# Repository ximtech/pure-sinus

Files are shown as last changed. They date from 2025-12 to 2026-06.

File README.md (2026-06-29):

# Pure-Sinus

The purpose of this project is to provide universal solutions for portable power stations, battery chargers, and inverters. 

## Table of Contents

- [Solr Mobile Power Management Platform](#solr-mobile-power-management-platform)
- [Solr Battery Controller](#solr-battery-controller)

# Solr Mobile Power Management Platform

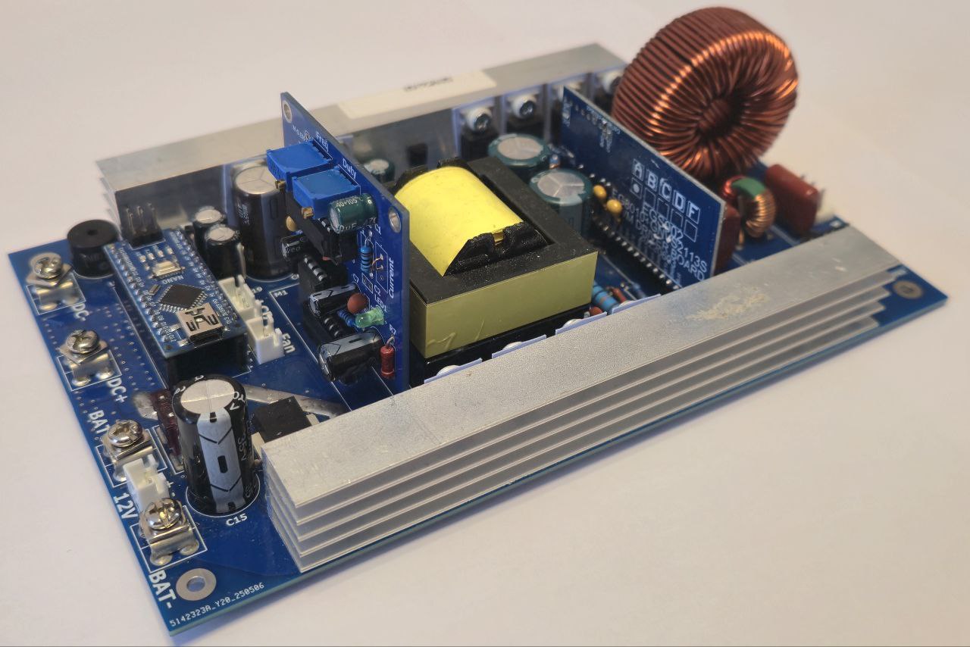
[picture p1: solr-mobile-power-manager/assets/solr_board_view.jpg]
solr_board_view


A compact and powerful battery-powered control electronics system with output power up to 500W. 
It can also be used as a standalone pure sine wave inverter converting 12V DC to 220V AC.
The system includes intelligent monitoring, protection, and management features for safe and reliable portable power delivery.

### Key Features

- **Pure Sine Wave AC Output**: 220V 50Hz AC up to 500W
- **500W Power Rating**: Sufficient for charging multiple devices and powering small appliances
- **DC Output**: 12V DC with up to 180W output for USB charging and DC loads
- **Lithium 3S 12V Battery Input**
- **Intelligent Power Management System**:
  - **Real-time battery voltage monitoring**: Low-battery protection with hysteresis
  - **Overload & Short-Circuit Protection**
  - **Dual Current Sensing**: Independent monitoring of DC output and AC inverter currents
  - **Dual Temperature Monitoring**: With automatic fan control and overheat protection
  - **Bidirectional DC**: DC output can also be used as a battery charger
  - **Low power consumption in standby mode**
- **Portable & Modular**: Designed as a platform for expanding functionality

### Use Cases

✓ **Device Charging**: Portable charging station for phones, tablets, and laptops  
✓ **Power Tools**: Supply stable AC power to cordless tools and equipment  
✓ **Emergency Power**: Backup power for critical devices during outages  
✓ **Outdoor Adventures**: Portable power for camping, RVs, and off-grid scenarios  
✓ **IoT & Smart Devices**: Reliable power for home automation and smart systems  

### Project Structure

```
pure-sinus/
└── solr-mobile-power-manager/         # Main folder
    ├── assets/                        # Images and visual assets
    ├── documents/                     # Datasheets and technical documentation
    ├── altium/                      # Altium PCB designs and circuit schematics
    │   ├── inverter_12V_220V_500W/    # Main inverter/power station board
    │   │   ├── Fabrication Files/     # Gerber, BOM, and manufacturing files
    │   │   └── libs/                  # Component libraries for Altium Designer
    │   └── tl494_pwm_controller/      # Dedicated PWM controller module
    │       ├── Fabrication Files/     # Gerber, BOM, and manufacturing files
    │       └── libs/                  # Component libraries for Altium Designer
    └── software/                      # PlatformIO firmware and control logic
        └── inverter-controller/       # Arduino firmware (PlatformIO-based)
            ├── src/                   # Source code files
            ├── include/               # Header files and configuration
            ├── lib/                   # Custom and external libraries
            ├── test/                  # Unit tests
            └── platformio.ini         # PlatformIO project configuration
```

### Hardware Specifications

### Main Components

- **Microcontroller**: Arduino Nano (ATmega328P)
- **PWM Controller**: TL494 PWM IC (with custom dedicated module)
- **Pure Sinus Driver**: EGS002
- **Current Sensors**: 
  - ACS712 30A Hall-effect current sensor DC
  - ACS758 100A Hall-effect current sensor AC
- **Temperature Sensors**: LM35
- **Output Transformer**: EC42-20 High-frequency SMPS transformer (12V→380V conversion)

### Hardware Assembly

### 1. TL494 PWM Module Assembly And Setup

- `pwm_controller_board.rar` contains all required files for PCB manufacturing the TL494 PWM module and located in `/altium/tl494_pwm_controller/Fabrication Files`
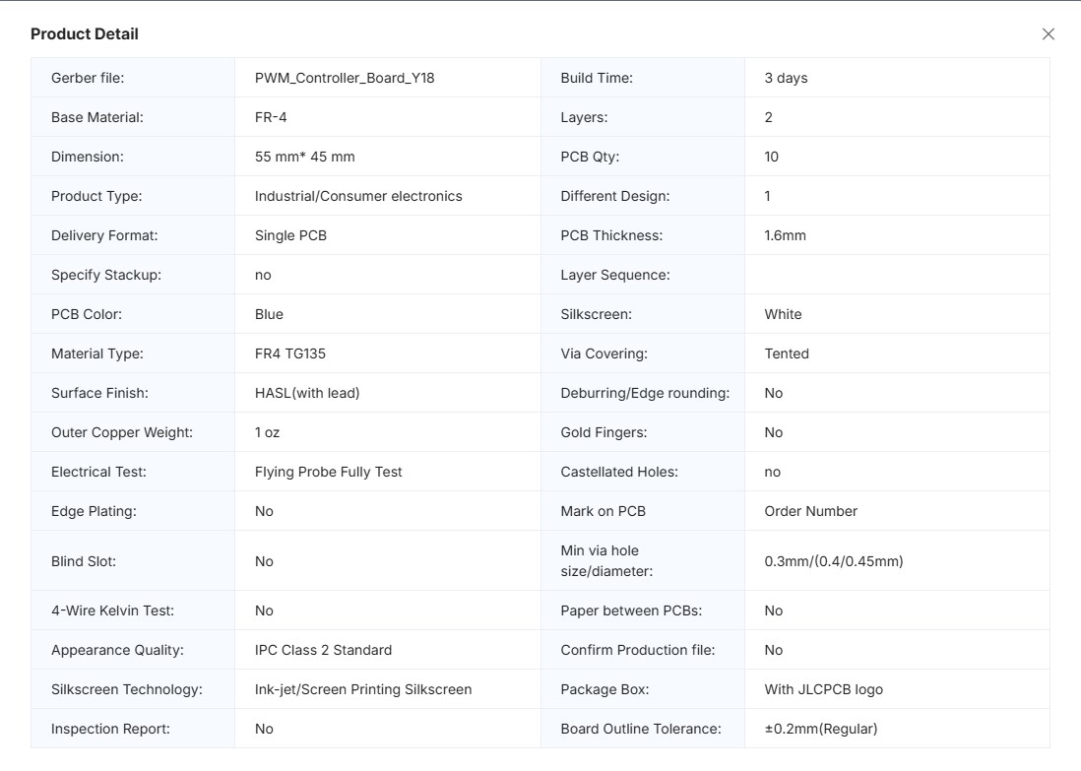
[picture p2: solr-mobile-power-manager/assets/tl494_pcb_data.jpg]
pcb_request_data
- 
- Follow the provided BOM and Gerber files to fabricate and assemble the PWM module
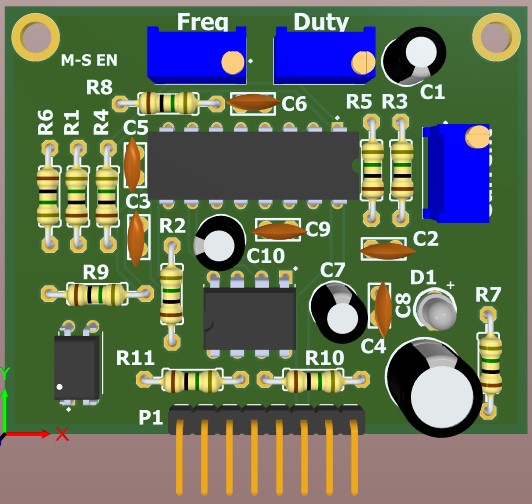
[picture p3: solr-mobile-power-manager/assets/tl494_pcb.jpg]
tl494_pcb
- 
- PWM module setup: 
    - Connect 12V power supply to `+12V` and `GND`
    - Set the frequency to `32kHz` for outputs `OutA` and `OutB` using potentiometer `Freq`
    - Adjust potentiometer `Duty` for `42%` duty cycle at no load
    - No need to configure current limiter, so `I-Sense` pin can be connected directly to ground
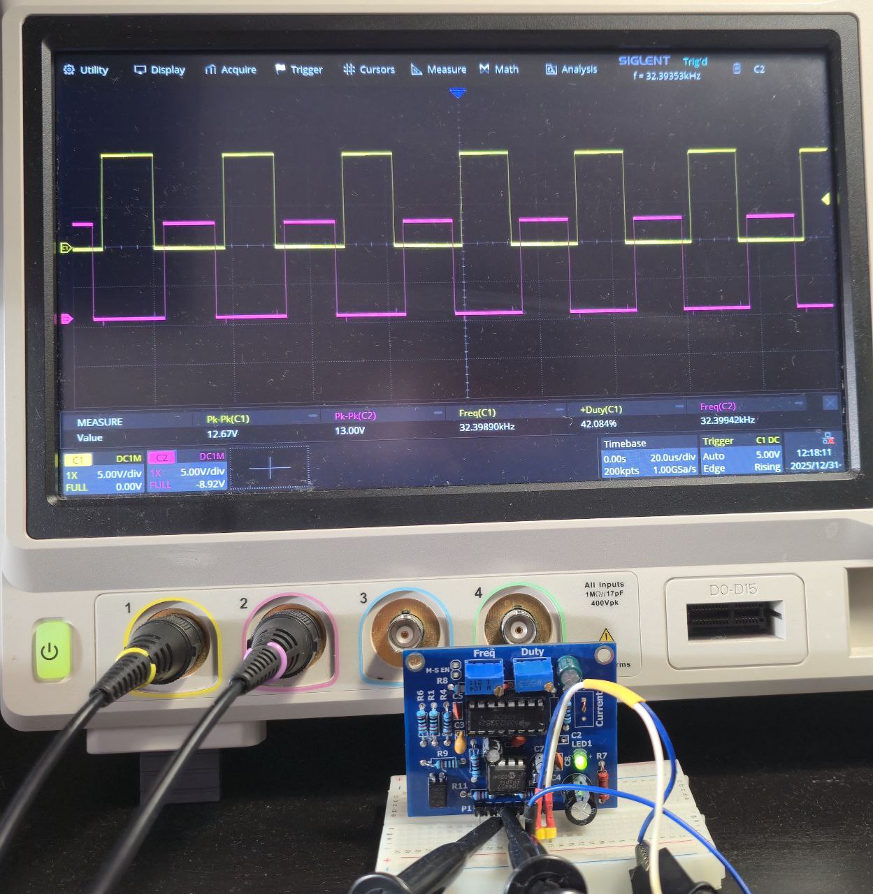
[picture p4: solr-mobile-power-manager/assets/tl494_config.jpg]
tl494_config
- 

### 2. EGS002 Driver Module Setup

The EGS002 module handles pure sinus wave generation
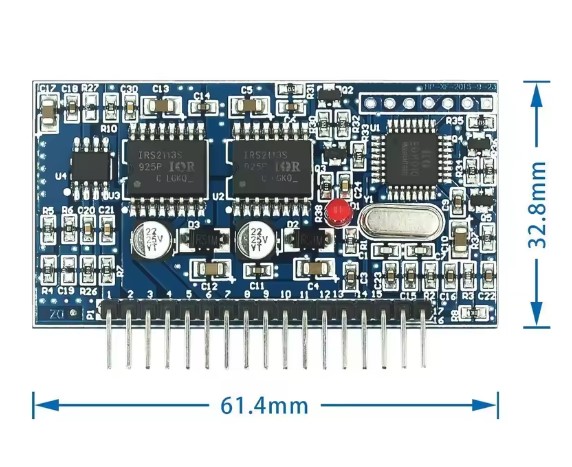
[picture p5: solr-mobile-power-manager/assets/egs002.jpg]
egs_pcb
- 
- Solder `JP8` jumper to `JP4`, to set dead time for `1.0us`
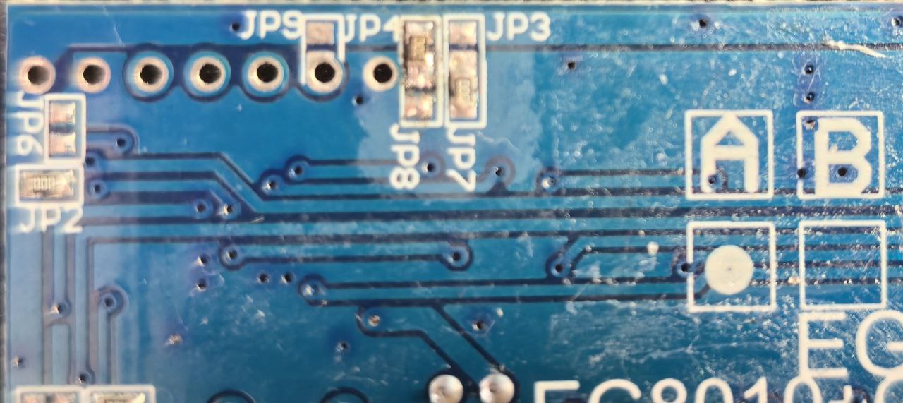
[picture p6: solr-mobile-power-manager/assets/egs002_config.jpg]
egs_pcb_config
- 
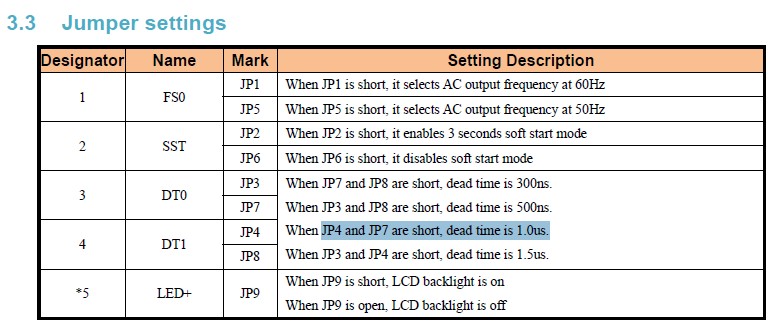
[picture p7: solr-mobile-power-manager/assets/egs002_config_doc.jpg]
egs_pcb_config_doc
- 
- No additional configuration is required

### 3. Inverter Board Assembly And Setup

- `inverter_board.rar` contains all required files for PCB manufacturing the board and located in `/altium/inverter_12V_220V_500W/Fabrication Files/`
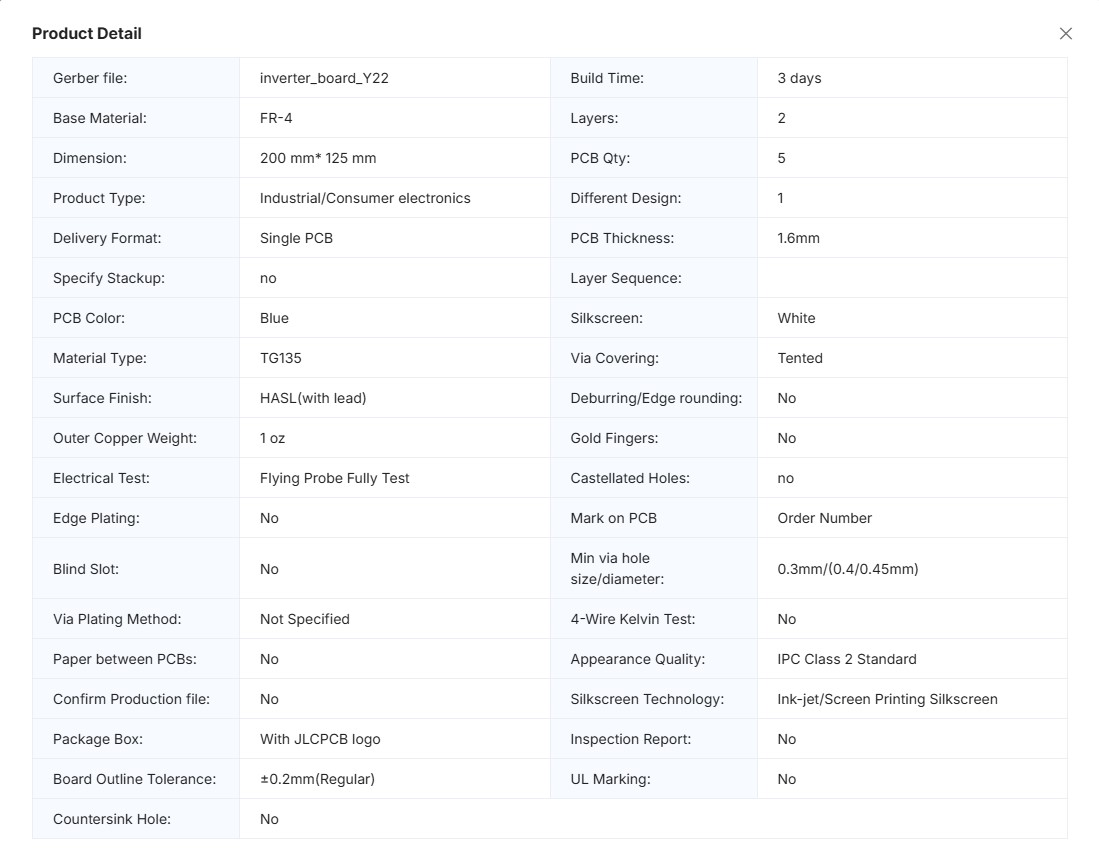
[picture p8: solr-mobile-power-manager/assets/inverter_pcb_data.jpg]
inverter_pcb_request_data
- 
- Follow the provided BOM and Gerber files to fabricate and assemble the PCB
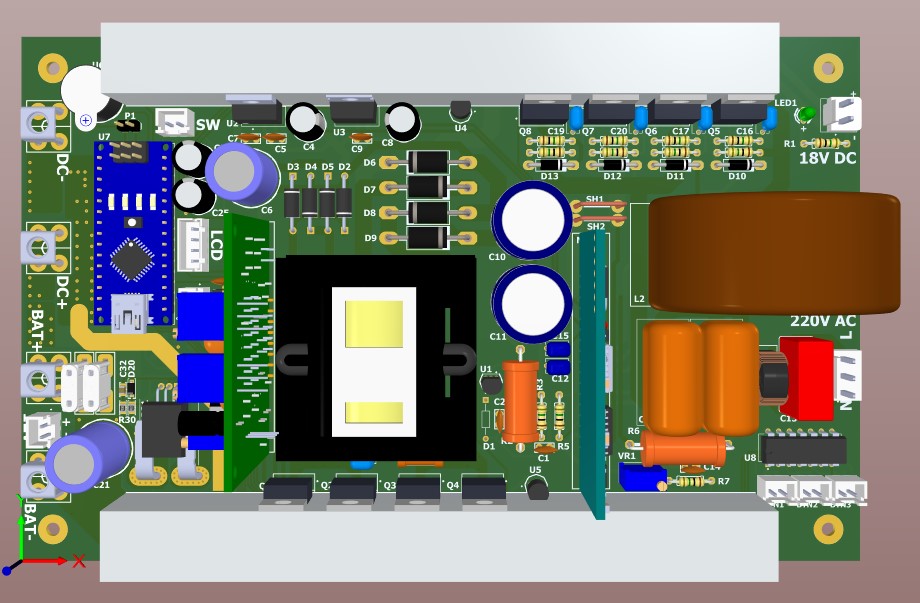
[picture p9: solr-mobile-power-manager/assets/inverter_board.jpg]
inverter_board
- 

### Assembly Steps

1. First, solder all SMD components on top and bottom layers
2. Solder all components, except `C6, C10, C11, T1, C21, M1 and M2`
3. Place heat sink `HS1` and `HS2`, then solder MOSFETs and LM78xx, secure with screws and isolating pads
4. Solder all other components except driver modules and Arduino
5. ***Note:*** It is recommended to use sockets for the microcontroller and driver modules for easy replacement and troubleshooting.
6. Then, connect/solder the `Arduino` and `TL494 PWM module`
7. Program the Arduino with the provided firmware
8. Connect laboratory power supply to `12V` input, set the current limit to `4-5A`, set `J8` switch and power on the board
9. Measure HV output voltage, it should be `400V DC` with no load and no `EGS002` module connected
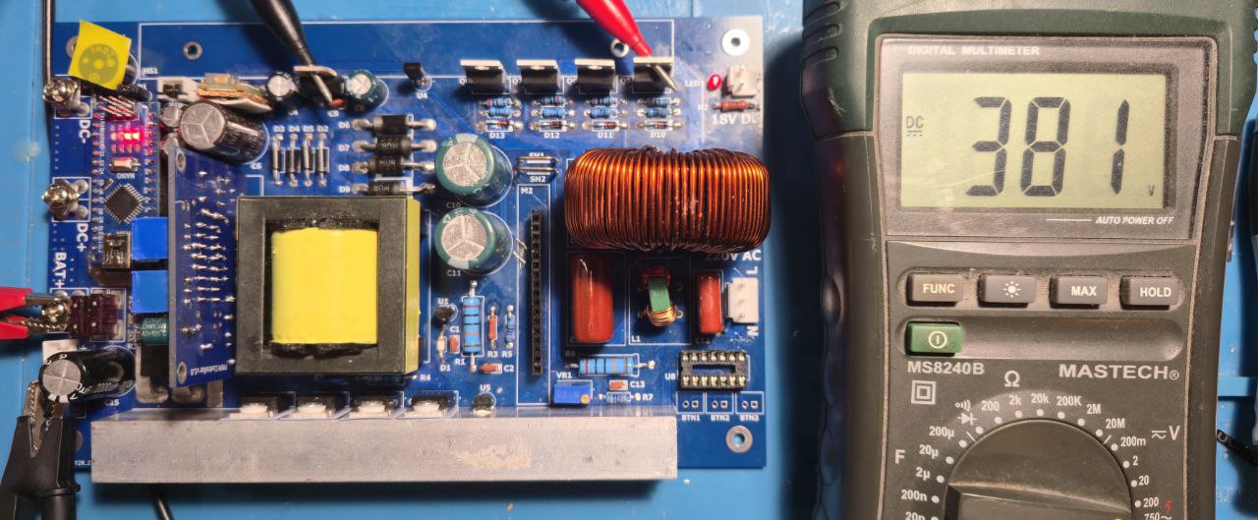
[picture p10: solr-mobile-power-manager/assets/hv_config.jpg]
hv_config
- 
10. Turn off power supply and wait(`R2` also used as bleed resistor) or discharge HV capacitors `C10` and `C11` before connecting the `EGS002` module
11. Connect the `EGS002`, run the next time. `EGS002` led should be on continuously indicating normal operation
12. Measure the output `AC` voltage, adjust the `VR1` potentiometer to set output voltage to `230V AC`
13. Check output `AC` waveform with oscilloscope, it should be a clean sine wave, also check with a load connected
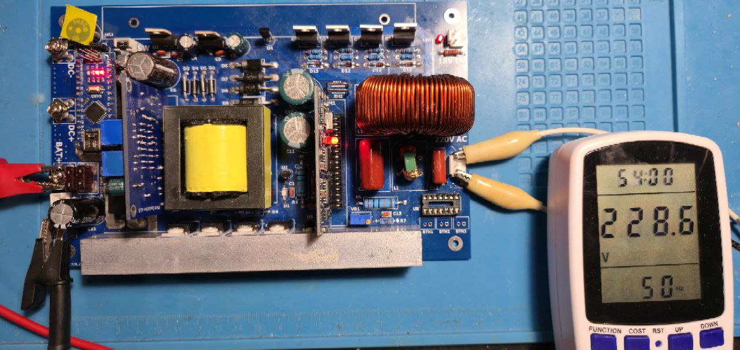
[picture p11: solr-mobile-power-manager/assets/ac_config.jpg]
ac_config
- 
14. Check `DC` voltage on `DC-` and `DC+` outputs, it should be `12V DC`
15. Connect cooling fan: it should run for a short time on power on, during system self-check
16. Then, set debug switch `P1` to on. Check ACS current sensors outputs, adjust if needed
17. Finally, glue thermal sensors to heat sinks using thermal adhesive glue (`heatsinkplaster`)
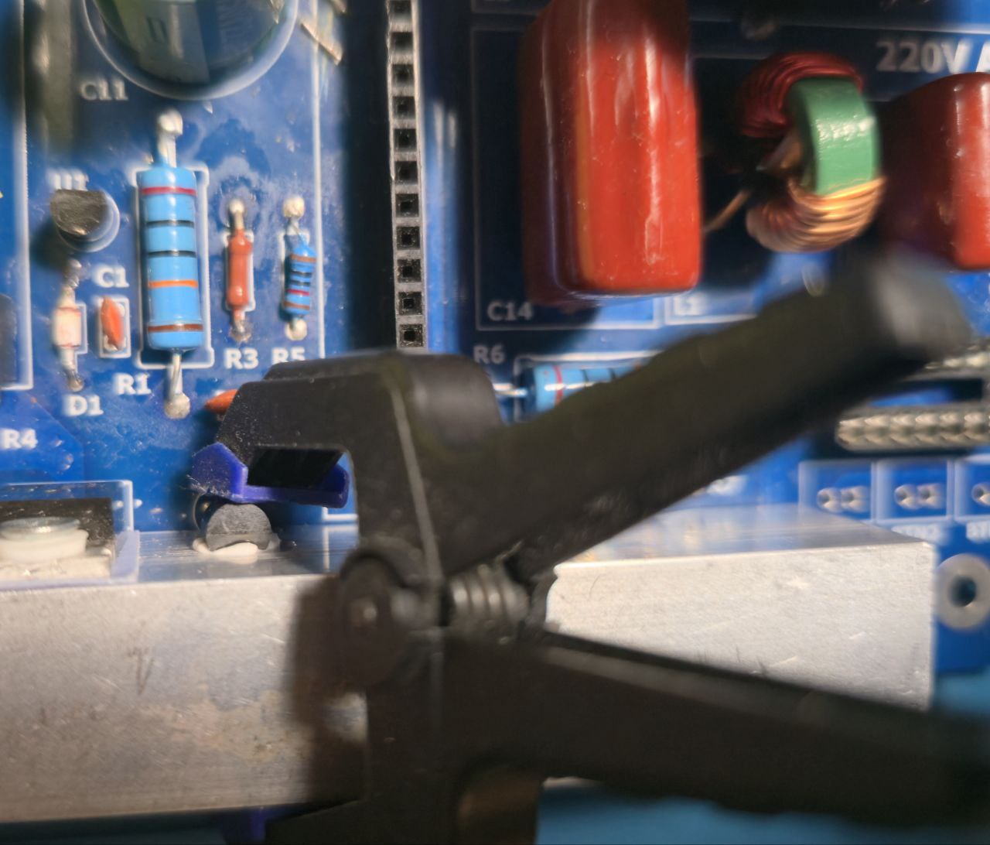
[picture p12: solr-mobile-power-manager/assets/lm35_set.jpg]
lm35_set
- 

### PCB Components
- Heat Sinks **HS1 and HS2** `150x19.7x15.6mm`: [link Aliexpress](https://www.aliexpress.com/item/1005004124759503.html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)
- Transformer **T1** `12V To 0-220V-380V 18V 500W EC42`: [link Aliexpress](https://www.aliexpress.com/item/1005003166892846.html?spm=a2g0o.order_list.order_list_main.5.2afd1802XkXKQq)
- Inductor **L2** `1.5 V. 2mH`: [link Aliexpress](https://www.aliexpress.com/item/1005006733553679.html?spm=a2g0o.order_list.order_list_main.382.6bd81802CETRoA)
- Choke filter **L1** `5A`: [link Aliexpress](https://www.aliexpress.com/item/33005799242.html?spm=a2g0o.order_list.order_list_main.65.6bd81802CETRoA)
- Capacitors **C10 and C11** `100uF 450V`: [link Aliexpress](https://www.aliexpress.com/item/1005006810057095.html?spm=a2g0o.order_list.order_list_main.362.6bd81802CETRoA)
- Shunt Resistor **SH1 and SH2** `20mR 1x10`: [link Aliexpress](https://www.aliexpress.com/item/1005005512229757.html?spm=a2g0o.order_list.order_list_main.372.6bd81802CETRoA)
- Screw terminal connectors **J3, J4, J5, J6**: [link Aliexpress](https://www.aliexpress.com/item/1005007060857910.html?spm=a2g0o.order_list.order_list_main.377.6bd81802CETRoA)
- Fuses **F1, F2** `25A`: [link Aliexpress](https://www.aliexpress.com/item/1005003956737422.html?spm=a2g0o.order_list.order_list_main.347.6bd81802CETRoA)
- The complete Bill of Materials (BOM) can be found in the `/altium/inverter_12V_220V_500W/Fabrication Files/` directory as `BOM_Inverter_12V_220V_500W.xlsx`.

### Firmware Architecture

Built with **PlatformIO** and **Arduino Framework** targeting Arduino Nano `ATmega328P`.

**Debug**:
- **When debug switch set**: 9600 baud UART can be used for monitoring and troubleshooting

## Safety Considerations And Warnings

### ⚠️ High Voltage Warning

This project operates with dangerous voltages

## Next Version Improvements

- ⬜ **OLED display and controls**: Add an OLED display and control buttons for monitoring and outputs on/off control
- ⬜ **Multi-Output USB**: Integrate USB-C and USB-A charging ports with PD protocol support, with up to 100W
- ⬜ **Battery Chemistry Flexibility**: Support for LiFePO4, Lead-acid, and other battery types
- ⬜ **Solar Input**: Add MPPT/PWM solar charge controller for renewable energy integration

---

# Solr Battery Controller

A universal `DC 12V 30A` battery controller.
The compact PCB design provides robust protection against battery over-discharge and over-current conditions,
ensuring maximum battery longevity and optimal performance with integrated power on delay feature.

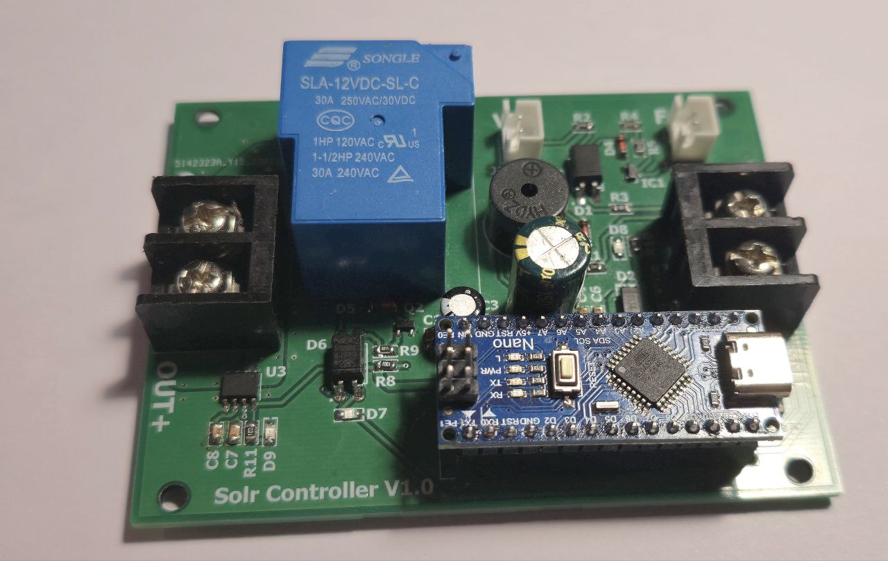
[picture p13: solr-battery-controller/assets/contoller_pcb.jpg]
solr_controller_pcb


### Key Features

- **Universal 12V Battery Compatibility**: Easy to set for various 12V battery types
- **Low Voltage Protection**: Detects and prevents dangerous voltage drops
- **Overcurrent Protection**: Output load disconnection on excessive current draw
- **Power On Delay**: Auto recovery after power interruptions with hysteresis, battery should be charged at least 10% for power on 
- **Mosfet Output**: Additional battery output that can be used for powering external devices or loads (`OUT` connector)
- **Charger Input**: Advanced charging algorithm for 12V batteries (`CHG` connector)
  - CV CC charger required (`XL4015` module), set charging voltage: 14.4V for SLA, 12.6V for Li-ion
- **Reverse Polarity Protection**
- **Compact Design**: 94mm x 70mm

### Project Structure

```
solr-battery-controller/               # Battery controller folder
├── assets/                            # Images and visual assets
├── documents/                         # Datasheets and technical documentation
├── altium/                            # Altium PCB designs and circuit schematics
│   └── solr-controller-base/          # Main controller board
│       ├── Fabrication Files/         # Gerber, BOM, and manufacturing files
│       └── *.IntLib                   # Component libraries for Altium Designer
└── software/                          # Firmware and control logic
    └── solr-controller-base/          # Arduino firmware (PlatformIO-based)
        ├── src/                       # Source code files
        ├── include/                   # Header files and configuration
        ├── lib/                       # Custom and external libraries
        ├── test/                      # Unit tests
        └── platformio.ini             # PlatformIO project configuration
```

### PCB Assembly

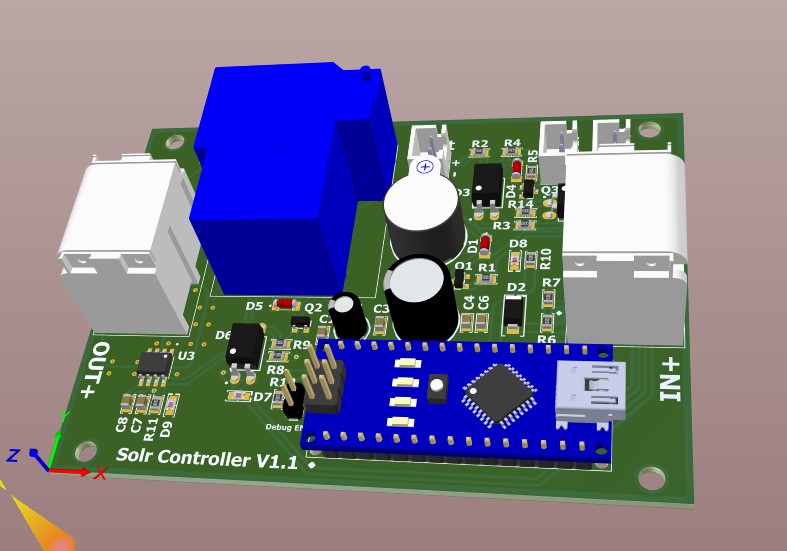
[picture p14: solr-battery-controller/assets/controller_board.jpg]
solr_controller_pcb
- 
- `solr-controller-board.rar` contains all required files for PCB manufacturing the board and located in `/altium/solr-controller-base/Fabrication Files/`
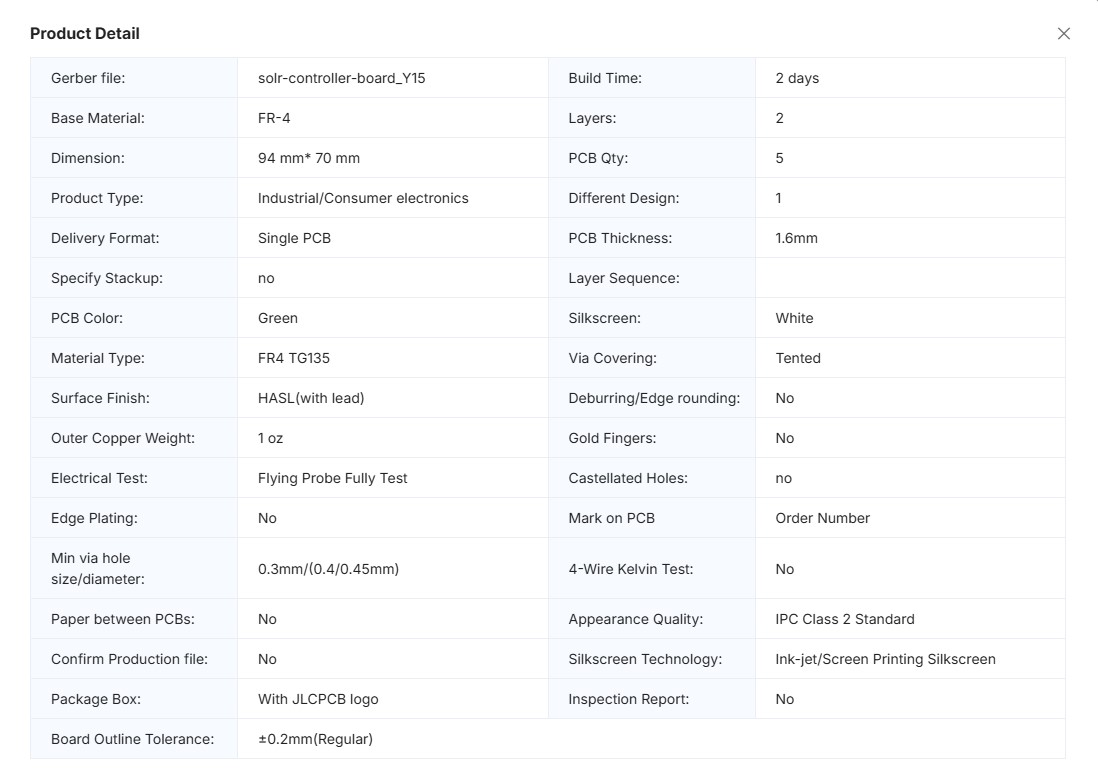
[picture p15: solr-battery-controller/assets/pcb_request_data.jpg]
solr_controller_pcb
- 

### PCB Components

- Relay **K1** `12V 30A`: [link Aliexpress](https://www.aliexpress.com/item/1005004371446685.html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)
- Connectors **J3 J4** `HB9500 2pin` : [link Aliexpress](https://www.aliexpress.com/item/1005008336461654.html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,scm-url:1007.40050.354490.0,pvid:bdbd0872-ae3c-45be-8bcf-08dd0156c3fc,tpp_buckets:668%232846%238111%231996&pdp_ext_f=%7B%22order%22%3A%22-1%22%2C%22eval%22%3A%221%22%2C%22sceneId%22%3A%2230050%22%2C%22fromPage%22%3A%22recommend%22%7D&pdp_npi=6%40dis%21EUR%210.50%210.50%21%21%210.58%210.58%21%40211b613917671256503675517e5ba9%2112000044644274242%21rec%21LV%21143434442%21XZ%211%210%21n_tag%3A-29919%3Bd%3A4c3c036e%3Bm03_new_user%3A-29895&utparam-url=scene%3ApcDetailTopMoreOtherSeller%7Cquery_from%3A%7Cx_object_id%3A1005008336461654%7C_p_origin_prod%3A)
- Current sensor **U3** `ACS712 30A`: [link Aliexpress](https://www.aliexpress.com/item/1005008877256845.html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)
- MCU **U2**: Arduino Nano (ATmega328P)
- The complete Bill of Materials (BOM) can be found in the `/altium/solr-controller-base/Fabrication Files/` directory as `BOM_Solr_Battery_Controller.xlsx`.

### Firmware Architecture

Built with **PlatformIO** and **Arduino Framework** targeting Arduino Nano `ATmega328P`.

**Debug**:
- **When debug switch set** `P1`: 9600 baud UART can be used for monitoring and troubleshooting

## Next Version Improvements

- ✅ **Battery Chemistry Flexibility**: Support for SLA, Li-ion

---

# Solr Button module

Universal two-button PCB module for controlling Solr input, also can be used for other applications. 
The module is designed to be compact and easy to integrate into various projects.

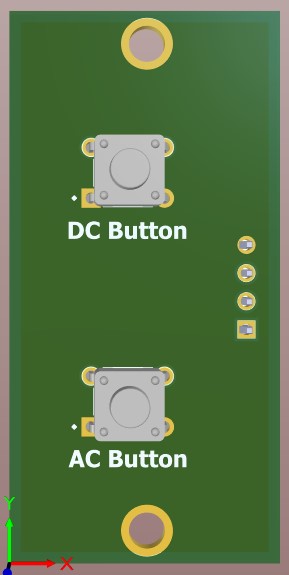
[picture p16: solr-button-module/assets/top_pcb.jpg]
solr_button_top_pcb
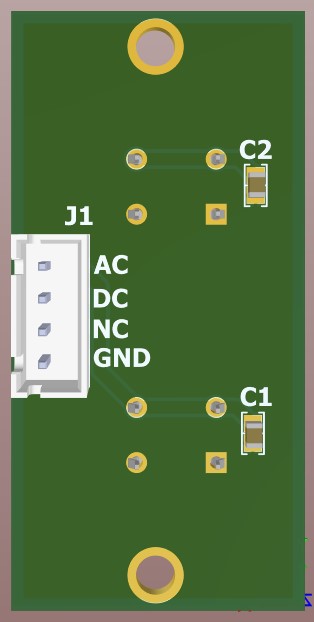
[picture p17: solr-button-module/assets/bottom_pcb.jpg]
solr_button_bottom_pcb


**Note:** Button dimensions are `6mm x 6mm` height `5mm`

---

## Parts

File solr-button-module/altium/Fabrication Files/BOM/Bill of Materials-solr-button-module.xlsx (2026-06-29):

Quantity | Designator | Comment | Footprint
2 | C1, C2 | 0.1µF | CAP 0805_2012
1 | J1 | B4B-XH-AM_(LF)(SN) | JST_B4B-XH-AM_(LF)(SN)
2 | S1, S2 | TL1105AF160Q | SW_TL1105AF160Q

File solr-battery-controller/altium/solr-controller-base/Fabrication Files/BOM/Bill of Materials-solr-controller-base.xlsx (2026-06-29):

Quantity | Designator | Comment | Footprint
3 | C1, C4, C7 | 0.1µF | CAP 0805_2012
1 | C2 | 100uF | MY_E5-13mm
2 | C3, C6 | 10 µF | CAP 0805_2012
1 | C5 | 1000u | MY_E5-13mm
1 | C8 | 1000 pF | CAP 0805_2012
4 | D1, D4, D5, D11 | LL4148 | DIO_LL4148
1 | D2 | SS23-TP | DO214AC SMA
3 | D3, D6, D10 | LTV-817S-TA | LITEON LTV-817
3 | D7, D8, D9 | Red | LED 0805_2012 RED
3 | J1, J2, J5 | B2B-XH-A(LF)(SN) | JST_B2B-XH-A(LF)(SN)
2 | J3, J4 | 5-1437648-7 | TE_5-1437648-7
1 | K1 | SLA-12VDC-SL-C | RELAY_SLA-12VDC-SL-C
1 | P1 | Header 2 | My_1X02
2 | Q1, Q2 | MMSS8050-L-TP | MCCSEMI SOT-23-3
1 | Q3 | DMG3406L-7 | DIODES SOT-23-3
1 | Q4 | AOD4184A | DPAK228P994X240-4N
2 | R1, R12 | 10 kOhms | RES 0805_2012
4 | R2, R5, R13, R16 | 4.7 kOhms | RES 0805_2012
5 | R3, R8, R10, R11, R14 | 1 kOhms | RES 0805_2012
2 | R4, R15 | 100 Ohms | RES 0805_2012
1 | R6 | 30 kOhms | RES 0805_2012
1 | R7 | 7.5 kOhms | RES 0805_2012
1 | R9 | 510 Ohms | RES 0805_2012
1 | U1 | Buzzer small | My_Buzzer
1 | U2 | Arduino Nano | MODULE_ARDUINO_NANO_A000005
1 | U3 | ACS712ELCTR30AT | SOIC127P600X175-8N

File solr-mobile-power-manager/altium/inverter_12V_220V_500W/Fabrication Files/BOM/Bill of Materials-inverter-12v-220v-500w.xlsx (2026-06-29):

Quantity | Designator | Comment | Footprint
6 | C1, C2, C5, C7, C9, C14 | 100nF | My_cap100n
1 | C3 | 10nF 1kV | CAP_RDER73A103K2K1H03B
2 | C4, C8 | 470uF | MY_E3.5-8mm
1 | C6 | 1000uF | MY_E5-13mm
2 | C10, C11 | 100uF | MY_E7.5-18mm
2 | C12, C15 | 10uF 25V | CAPRB500W50L550T350H600
1 | C13 | 100nF | MY_E8.4-15mm
4 | C16, C17, C19, C20 | 1nF 1kV | CAP_RDER73A103K2K1H03B
2 | C18, C42 | 2.2uF 630V | CAPRR2250W80L2530T1240H1770
1 | C21 | 2200uF | MY_E5-13mm
14 | C22, C23, C26, C27, C28, C29, C30, C32, C34, C35, C37, C41, C43, C44 | 0.1µF | CAP 0805_2012
2 | C24, C25 | 220uF | MY_E3.5-8mm
4 | C31, C33, C36, C39 | 10µF | CAP 0805_2012
1 | C38 | 100 pF | CAP 0805_2012
1 | C40 | 1000 pF | CAP 0805_2012
1 | D1 | BZX55B20_R0G | DIOAD928W47L399D179
4 | D2, D3, D4, D5 | HER207G | DIOAD1300W80L670D310
4 | D6, D7, D8, D9 | MUR460 | My_DO201-15
4 | D10, D11, D12, D13 | 1N4148 | My_DO41
3 | D14, D18, D21 | LTV-817S-TA | LITEON LTV-817
4 | D15, D17, D19, D22 | LL4148 | DIO_LL4148
1 | D16 | SS23-TP | DO214AC SMA
1 | D20 | MMSZ5231CT1G | SOD-123
2 | F1, F2 | 25A | Mini Car Blade Fuse
2 | HS1, HS2 | HSINK-150-20-16MM | HSINK-150-20-16MM
1 | J1 | 18V | VALCON_VH396-02S-010
1 | J2 | 220 VAC | JST_B3P-VH(LF)(SN)
1 | J3 | BATT + | Keystone 7767
1 | J4 | DC + | Keystone 7767
1 | J5 | BATT - | Keystone 7767
1 | J6 | DC - | Keystone 7767
1 | J7 | Out 12V | JST_B2B-XH-A(LF)(SN)
1 | J8 | On/Off Switch | JST_B2B-XH-A(LF)(SN)
1 | J9 | Buttons | JST_B4B-XH-AM_(LF)(SN)
1 | J10 | VH396-02S-010 | VALCON_VH396-02S-010
1 | J12 | Fan | JST_B2B-XH-A(LF)(SN)
1 | J13 | I2C | JST_B4B-XH-AM_(LF)(SN)
1 | L1 | 2mH | WE-CMBNC_XS_7448010911
1 | L2 | 2mH | 184125
1 | LED1 |  | LED3MM
1 | M1 | TL494 PWM Module | TL494-PWM-MODULE
1 | M2 | EGS002 | EGS002
1 | P1 | Debug EN | My_1X02
4 | Q1, Q2, Q3, Q4 | IRF3205PBF | INF-PG-TO-220AB
4 | Q5, Q6, Q7, Q8 | IRF840PBF | VISH-TO-220AB-3
6 | Q9, Q10, Q11, Q12, Q14, Q15 | AOD4184A | DPAK228P994X240-4N
1 | Q13 | MMSS8050-L-TP | MCCSEMI SOT-23-3
1 | Q16 | DMG3406L-7 | DIODES SOT-23-3
1 | R1 | 2.2 kOhms | MY_(0.25w)_0207_10
2 | R2, R6 | 200 kOhms | MY_(2w)_0617_22
1 | R3 | 3.3 kOhms | MY_(0.25w)_0207_10
1 | R4 | 4.7 Ohms | MY_(0.5w)_0411_15
2 | R5, R7 | 10 kOhms | MY_(0.25w)_0207_10
4 | R8, R9, R12, R13 | 22 Ohms | MY_(0.25w)_0207_10
4 | R10, R11, R14, R15 | 5.6 kOhms | MY_(0.25w)_0207_10
3 | R16, R23, R35 | 1 kOhms | RES 0805_2012
3 | R17, R27, R37 | 100 Ohms | RES 0805_2012
4 | R18, R28, R34, R38 | 4.7 kOhms | RES 0805_2012
8 | R19, R20, R21, R24, R25, R26, R33, R36 | 10 kOhms | YAGEO RES 0805_2012
2 | R22, R29 | 10 kOhms | RES 0805_2012
1 | R30 | 30 kOhms | RES 0805_2012
1 | R31 | 7.5 kOhms | RES 0805_2012
1 | R32 | 120 Ohms | YAGEO RES 0805_2012
2 | SH1, SH2 | 20 mOhms | WIRE-SHUNT
1 | T1 | EC42/EE42 | EC42/EE42
1 | U1 | TL431ILPG | TO92127P520H660-3
1 | U2 | LM7812CT | TO254P1054X470X1955-3
1 | U3 | LM7805CT | TO254P1054X470X2600-3
2 | U4, U5 | LM35DZ TO-92 | TO92127P521H735-3
1 | U6 | Buzzer small | My_Buzzer
1 | U7 | Arduino Nano | MODULE_ARDUINO_NANO_A000005
1 | U8 | CD74HC14E | DIP794W45P254L1969H508Q14
1 | U9 | TLC2272QDR | SOIC127P599X175-8N
1 | U10 | ACS712ELCTR30AT | SOIC127P600X175-8N
1 | U11 | ACS758 | XDCR_ACS758
1 | VR1 | 10k | TRIM_3296W-1-502

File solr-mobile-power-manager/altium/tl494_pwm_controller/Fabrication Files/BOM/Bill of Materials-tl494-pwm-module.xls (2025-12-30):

Quantity | Designator | Comment | Footprint
3 | C1, C7, C10 | 4.7uF | MY_E2.5-5mm
5 | C2, C3, C5, C8, C9 | 100nF | My_cap100n
1 | C4 | 220uF | MY_E3.5-8mm
1 | C6 | 1nF | My_cap100n
1 | D1 | LED | My_LED3MM
1 | P1 | Header 8 | MY_MA08-1W
6 | R1, R2, R6, R9, R10, R11 | 10 kOhms | MY_(0.25w)_0207_10
1 | R3 | 15 kOhms | MY_(0.25w)_0207_10
1 | R4 | 1 kOhms | MY_(0.25w)_0207_10
1 | R5 | 5.6 kOhms | MY_(0.25w)_0207_10
1 | R7 | 2.2 kOhms | MY_(0.25w)_0207_10
1 | R8 | 2 kOhms | MY_(0.25w)_0207_10
1 | U1 | PC817 | DIP762W50P254L495H455Q4
1 | U2 | TL494IN | DIP794W45P254L1969H508Q16
1 | U3 | MIC4427ZN | DIP787W46P254L927H533Q8
2 | VR1, VR2 | 10 kOhms | TRIM_3296W-1-502
1 | VR3 | 100 kOhms | TRIM_3296W-1-502

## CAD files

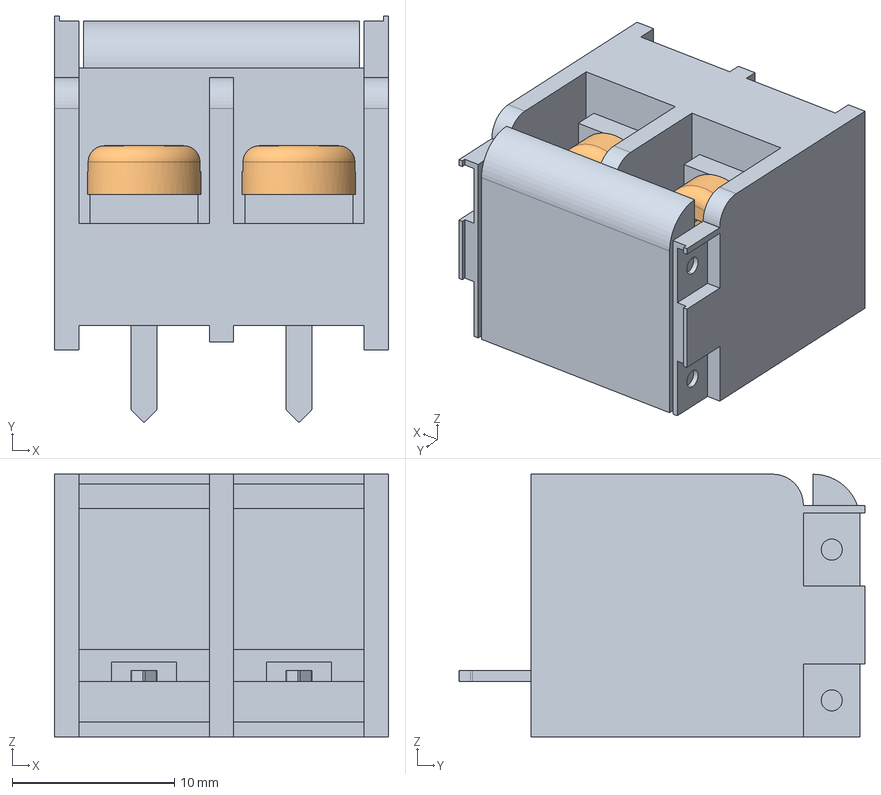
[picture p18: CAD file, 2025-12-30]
solr-battery-controller/altium/solr-controller-base/hb9500_asm.stp
20.6 x 25.0 x 16.2 mm
HB9500-1
M5X6 x 2

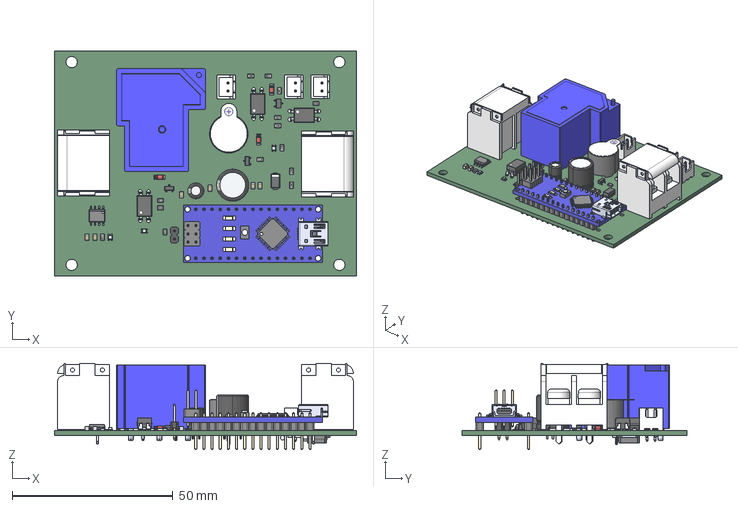
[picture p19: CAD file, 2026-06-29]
solr-battery-controller/altium/solr-controller-base/Fabrication Files/ExportSTEP/PCB.step
94.0 x 70.0 x 26.8 mm

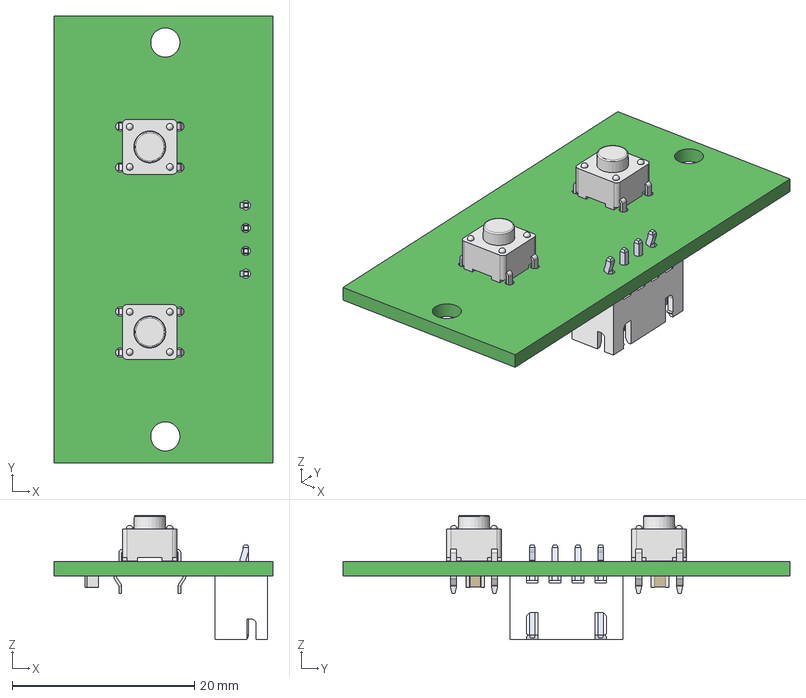
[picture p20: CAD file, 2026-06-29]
solr-button-module/altium/Fabrication Files/ExportSTEP/Buttons_PCB.step
24.0 x 49.0 x 13.6 mm

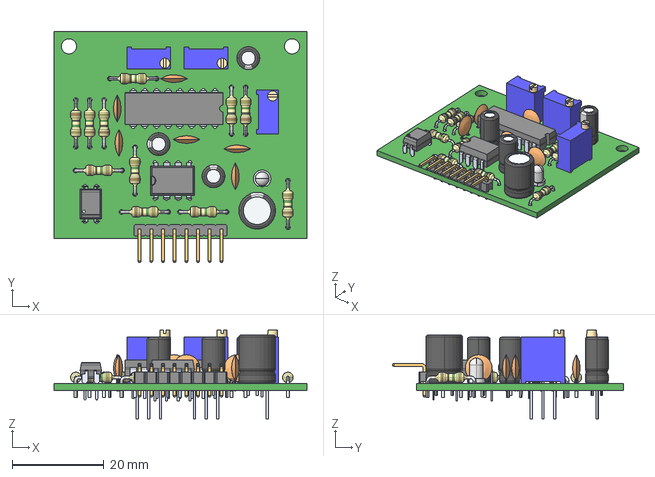
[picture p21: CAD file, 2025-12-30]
solr-mobile-power-manager/altium/tl494_pwm_controller/Fabrication Files/ExportSTEP/PCB.step
55.0 x 50.2 x 19.3 mm

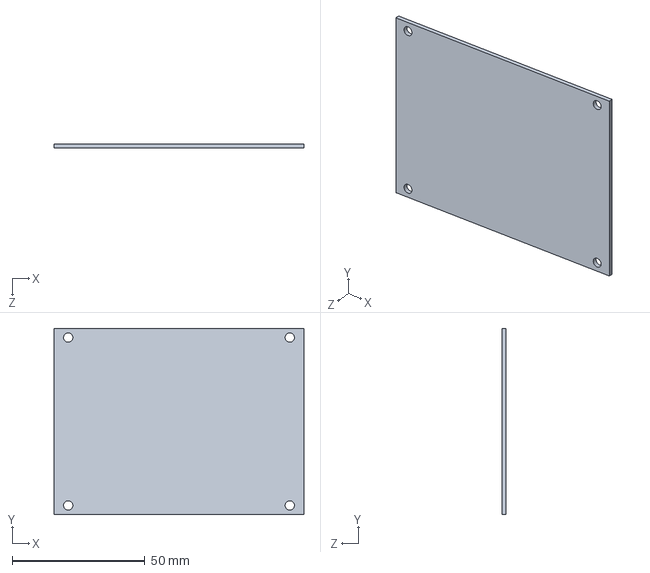
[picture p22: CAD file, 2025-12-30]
solr-battery-controller/altium/solr-controller-base/Board_Shape_Part.SLDPRT
94.0 x 70.0 x 1.60 mm

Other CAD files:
solr-battery-controller/altium/solr-controller-base/Board_Shape.DWG
solr-button-module/altium/Fabrication Files/ExportSTEP/PCB.step

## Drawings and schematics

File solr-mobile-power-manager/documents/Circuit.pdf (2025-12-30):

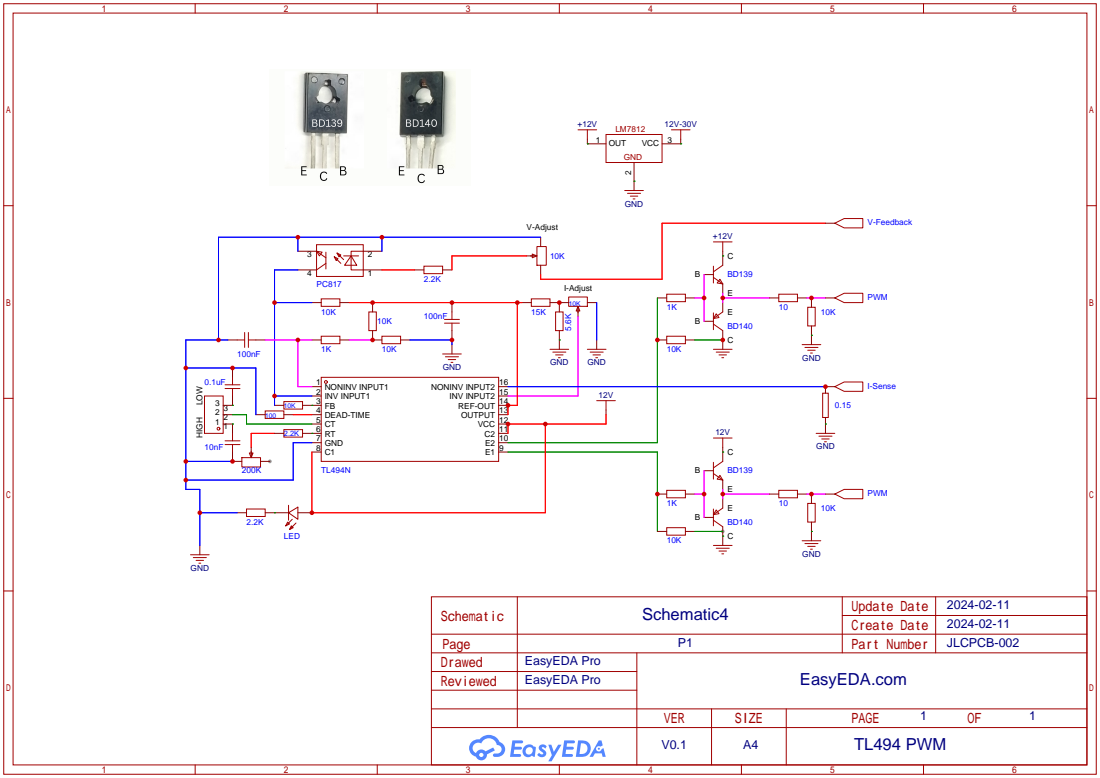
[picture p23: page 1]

E2 10 C2 11 VCC 12 OUTPUT 13 REF-OUT 14 INV INPUT2 15 NONINV INPUT2 16

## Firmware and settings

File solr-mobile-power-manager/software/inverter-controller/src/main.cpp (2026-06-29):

#include <Arduino.h>
#include <EnableInterrupt.h>

#include <Sound.h>
#include "ACS712.h"
#include "LM35IC.h"

#define DEBUG_ENABLE_PIN        9
#define BUILD_IN_LED_PIN        13
#define BUZZER_PIN              10
#define AC_INVERTER_SWITCH_PIN  11
#define DC_LOAD_SWITCH_PIN      8
#define COOLING_FAN_PIN         3

#define AC_BUTTON_PIN   7
#define DC_BUTTON_PIN   6

#define VOLTAGE_SENSOR_PIN           A0
#define DC_CURRENT_SENSOR_PIN        A1
#define INVERTER_CURRENT_SENSOR_PIN  A2
#define TL494_LOAD_TEMP_SENSOR_PIN   A3
#define EGS002_LOAD_TEMP_SENSOR_PIN  A6

// Arduino NANO has 5.0 volt with a max ADC value of 1023 steps
#define MCU_SUPPLY_VOLTAGE          5.0f
#define ADC_RESOLUTION              1023.0f

#define VOLTAGE_READ_COUNT          4
#define MIN_BATTERY_VOLTAGE         9.9f    // 3.3V * 3S -> 0%
#define BATTERY_RECOVERY_VOLTAGE    10.8f  // 3.6V * 3S -> 10%
#define MAX_ALLOWED_BATTERY_VOLTAGE 12.9f
#define LOW_BATTERY_SIGNAL_COUNT    10

#define CURRENT_READ_CYCLES            50
#define MAX_DC_LOAD_CURRENT            15.0f
#define MAX_INVERTER_PRIMARY_CURRENT   30.0f
#define MAX_TOTAL_LOAD_CURRENT         30.0f
#define CURRENT_OVERLOAD_TIMEOUT_MS    (5 * 1000)
#define MAX_SEQUENTIAL_OVERLOAD_COUNT   4

#define TEMPERATURE_SAMPLING_COUNT      25
#define OVER_TEMPERATURE_TIMEOUT_MS     (5 * 60000)   // 5 minutes
#define TEMPERATURE_READ_INTERVAL_MS    (1 * 1000)    // read temperature every second
#define OVER_TEMPERATURE_SIGNAL_COUNT   10

typedef enum ControllerState{
    STATE_OK = 0,
    STATE_BATTERY_LOW,
    STATE_CURRENT_OVERLOAD,
    STATE_OVER_TEMPERATURE,
    STATE_FATAL_ERROR,  // short circuit in a load etc. Cannot recover
} ControllerState;

typedef enum CoolingFanSpeed {
    COOLING_FAN_OFF = 0,
    COOLING_FAN_LOW = 64,
    COOLING_FAN_MEDIUM = 128,
    COOLING_FAN_HIGH = 255,
} CoolingFanSpeed;

typedef enum TemperatureRange {
    TEMP_RANGE_NORMAL = 0,    // Below 35°C
    TEMP_RANGE_LOW = 35,      // 35-50°C
    TEMP_RANGE_MEDIUM = 50,   // 50-60°C
    TEMP_RANGE_HIGH = 60,     // 60-70°C
    TEMP_RANGE_MAX = 70,      // 70°C and above
} TemperatureRange;

/*
 * Two resistors divider of 30K and 7.5K
 *
 * Vbat     Vin      GND
 *  |        |        |
 *  +--[R1]--+--[R2]--+
 *
 *  R1 = 30kOhms
 *  R2 = 7.5kOhms
*/
static const float R1 = 30000;
static const float R2 = 7500;

static ACS712 dcLoadCurrentSensor(DC_CURRENT_SENSOR_PIN, MCU_SUPPLY_VOLTAGE, ADC_RESOLUTION, 66);            //ACS712 30A uses 66mV per A
static ACS712 inverterCurrentSensor(INVERTER_CURRENT_SENSOR_PIN, MCU_SUPPLY_VOLTAGE, ADC_RESOLUTION, 20);   // ACS758 100A uses 20mV per A

static LM35::LM35IC primaryTemperatureSensor = LM35::LM35IC(TL494_LOAD_TEMP_SENSOR_PIN, LM35::LM35D, 1.0, 0.0, MCU_SUPPLY_VOLTAGE);
static LM35::LM35IC secondaryTemperatureSensor = LM35::LM35IC(EGS002_LOAD_TEMP_SENSOR_PIN, LM35::LM35D, 1.0, 0.0, MCU_SUPPLY_VOLTAGE);

static ControllerState state = STATE_OK;
static float batteryVoltage = 0.0f;
static float dcLoadCurrent = 0.0f;
static float inverterLoadCurrent = 0.0f;
static double primarySideTemp = 0.0;
static double secondarySideTemp = 0.0;

static uint8_t errorSignalCounter = 0;
static uint64_t loadDisableTimeoutMs = 0;
static uint64_t previousTemperatureReadMs = 0;
static uint8_t sequentialOverloadCount = 0;
static uint64_t sequentialOverloadMs = 0;

static volatile boolean isAcInverterEnabled = false;
static volatile boolean isDcLoadEnabled = false;

static float getBatteryVoltage(uint16_t samplingCount);
static float getAcsLoadAmps(ACS712 acs);

static void ISR_DcButtonPressed();
static void ISR_AcInverterButtonPressed();

static void handleBatteryVoltage();
static void handleDcLoadCurrent();
static void handleInverterLoadCurrent();
static void handleTemperatureSensors();
static void handleControllerState();

static inline bool isDebugEnabled();
static inline void ledToggle();
static inline void inverterSwitchOn();
static inline void inverterSwitchOff();
static inline void dcLoadSwitchOn();
static inline void dcLoadSwitchOff();
static inline void disableAllOutputs();
static inline void setCoolingFanSpeed(CoolingFanSpeed adcValue);
static double getTemperature(LM35::LM35IC sensor);
static inline TemperatureRange getTemperatureRange(double temperature);

void setup() {
    Serial.begin(9600);
    pinMode(BUILD_IN_LED_PIN, OUTPUT);
    pinMode(AC_INVERTER_SWITCH_PIN, OUTPUT);
    pinMode(DC_LOAD_SWITCH_PIN, OUTPUT);
    pinMode(BUZZER_PIN, OUTPUT);
    pinMode(COOLING_FAN_PIN, OUTPUT);
    pinMode(DEBUG_ENABLE_PIN, INPUT_PULLUP);
    pinMode(VOLTAGE_SENSOR_PIN, INPUT);
    pinMode(DC_CURRENT_SENSOR_PIN, INPUT);
    pinMode(INVERTER_CURRENT_SENSOR_PIN, INPUT);
    pinMode(TL494_LOAD_TEMP_SENSOR_PIN, INPUT);
    pinMode(EGS002_LOAD_TEMP_SENSOR_PIN, INPUT);
    pinMode(AC_BUTTON_PIN, INPUT);
    pinMode(DC_BUTTON_PIN, INPUT);

    disableAllOutputs();

    while (!Serial);
    Serial.print("ACS712 lib version: ");
    Serial.println(ACS712_LIB_VERSION);
    delay(100);

    // set mid point for current sensors
    dcLoadCurrentSensor.autoMidPointDC(100);
    dcLoadCurrentSensor.incMidPoint();
    dcLoadCurrentSensor.suppressNoise(true);
    Serial.print("DC Load ACS MidPoint= ");
    Serial.println(dcLoadCurrentSensor.getMidPoint());

    inverterCurrentSensor.autoMidPointDC(100);
    Serial.print("INV Load ACS MidPoint= ");
    Serial.println(inverterCurrentSensor.getMidPoint());

    // stabilize values
    dcLoadCurrentSensor.mA_DC(100);
    inverterCurrentSensor.mA_DC(100);
    getBatteryVoltage(100);

    setCoolingFanSpeed(COOLING_FAN_HIGH);   // run fan at high speed for a moment to check it's working
    delay(100);
    setCoolingFanSpeed(COOLING_FAN_OFF);
    playStartupSound(BUZZER_PIN);
    isDcLoadEnabled = true; // enable a DC load by default, minimum current consumption on idle and battery meter power supply on startup

    enableInterrupt(DC_BUTTON_PIN, ISR_DcButtonPressed, RISING);
    enableInterrupt(AC_BUTTON_PIN, ISR_AcInverterButtonPressed, RISING);
}

void loop() {

    handleBatteryVoltage();
    handleDcLoadCurrent();
    handleInverterLoadCurrent();

    float totalLoadCurrent = dcLoadCurrent + inverterLoadCurrent;
    if (state == STATE_OK && totalLoadCurrent > MAX_TOTAL_LOAD_CURRENT) {
        disableAllOutputs();
        state = STATE_CURRENT_OVERLOAD; // total load too high
        sequentialOverloadCount++;
        loadDisableTimeoutMs = millis();
    }
    handleTemperatureSensors();
    handleControllerState();

    if (isDebugEnabled()) {
        Serial.print("V= ");
        Serial.print(batteryVoltage, 3);
        Serial.print(", DC Amps= ");
        Serial.print(dcLoadCurrent, 3);
        Serial.print(", Inv Amps= ");
        Serial.print(inverterLoadCurrent, 3);
        Serial.print(", Temp1= ");
        Serial.print(primarySideTemp);
        Serial.print("C");
        Serial.print(", Temp2= ");
        Serial.print(secondarySideTemp);
        Serial.print("C");
        Serial.println();
        delay(1000);
        return;
    }
    delay(state == STATE_OK ? 50 : 1000);
}

static void ISR_DcButtonPressed() { // No need to debounce, hardware debounce circuit is used
    if (state != STATE_OK) return;
    isDcLoadEnabled = !isDcLoadEnabled;

    if (isDcLoadEnabled) {
        dcLoadSwitchOn();
    } else {
        dcLoadSwitchOff();
    }
}

static void ISR_AcInverterButtonPressed() { // No need to debounce, hardware debounce circuit is used
    if (state != STATE_OK) return;
    isAcInverterEnabled = !isAcInverterEnabled;
    if (!isAcInverterEnabled) {
        inverterSwitchOff();
    }
}

static void handleBatteryVoltage() {
    if (state == STATE_FATAL_ERROR) return;

    batteryVoltage = getBatteryVoltage(VOLTAGE_READ_COUNT);
    if (batteryVoltage <= MIN_BATTERY_VOLTAGE) {
        state = STATE_BATTERY_LOW;
        disableAllOutputs();

    } else if (batteryVoltage > MAX_ALLOWED_BATTERY_VOLTAGE) {
        disableAllOutputs();
        state = STATE_FATAL_ERROR; // battery voltage too high, something is wrong
        fatalErrorSound(BUZZER_PIN);
    }
}

static void handleDcLoadCurrent() {
    if (state != STATE_OK || !isDcLoadEnabled) {
        dcLoadCurrent = 0.0f;
        return;
    }

    if (digitalRead(DC_LOAD_SWITCH_PIN) == LOW) {
        dcLoadSwitchOn();   // DC load disabled, but button state is ON. This can happen when recovering from error (low battery, overload, etc.) Turn it on to recover state
    }

    dcLoadCurrent = getAcsLoadAmps(dcLoadCurrentSensor);
    if (dcLoadCurrent > MAX_DC_LOAD_CURRENT) {
        disableAllOutputs();
        state = STATE_CURRENT_OVERLOAD;
        sequentialOverloadCount++;
        loadDisableTimeoutMs = millis();
    }
}

static void handleInverterLoadCurrent() {
    if (state != STATE_OK || !isAcInverterEnabled) {
        inverterLoadCurrent = 0.0f;
        return;
    }

    if (digitalRead(AC_INVERTER_SWITCH_PIN) == LOW) {
        disableInterrupt(AC_BUTTON_PIN);
        inverterSwitchOn();
        delay(1000);    // wait for inverter to start and stabilize current, otherwise we can get a false overload reading
        enableInterrupt(AC_BUTTON_PIN, ISR_AcInverterButtonPressed, RISING);
    }

    inverterLoadCurrent = getAcsLoadAmps(inverterCurrentSensor);
    if (inverterLoadCurrent > MAX_INVERTER_PRIMARY_CURRENT) {
        disableAllOutputs();
        state = STATE_CURRENT_OVERLOAD;
        sequentialOverloadCount++;
        loadDisableTimeoutMs = millis();
    }
}

static void handleTemperatureSensors() {
    if (state != STATE_OK) return;

    uint64_t currentMillis = millis();
    if ((currentMillis - previousTemperatureReadMs) >= TEMPERATURE_READ_INTERVAL_MS) {
        primarySideTemp = getTemperature(primaryTemperatureSensor);
        secondarySideTemp = getTemperature(secondaryTemperatureSensor);

        TemperatureRange primaryTempRange = getTemperatureRange(primarySideTemp);
        TemperatureRange secondaryTempRange = getTemperatureRange(secondarySideTemp);
        if (primaryTempRange == TEMP_RANGE_HIGH || secondaryTempRange == TEMP_RANGE_HIGH) {
            setCoolingFanSpeed(COOLING_FAN_HIGH);

        } else if (primaryTempRange == TEMP_RANGE_MEDIUM || secondaryTempRange == TEMP_RANGE_MEDIUM) {
            setCoolingFanSpeed(COOLING_FAN_MEDIUM);

        } else if (primaryTempRange == TEMP_RANGE_LOW || secondaryTempRange == TEMP_RANGE_LOW) {
            setCoolingFanSpeed(COOLING_FAN_LOW);

        } else if (primaryTempRange == TEMP_RANGE_MAX || secondaryTempRange == TEMP_RANGE_MAX) {
            disableAllOutputs();
            setCoolingFanSpeed(COOLING_FAN_HIGH);
            state = STATE_OVER_TEMPERATURE; // temperature too high
            loadDisableTimeoutMs = currentMillis;

        } else {
            setCoolingFanSpeed(COOLING_FAN_OFF);
        }
        previousTemperatureReadMs = currentMillis;
    }
}

static void handleControllerState() {
    if (state == STATE_OK || state == STATE_FATAL_ERROR) return;

    uint64_t currentMillis = millis();
    if (state == STATE_BATTERY_LOW && (batteryVoltage < BATTERY_RECOVERY_VOLTAGE)) { // battery charge should be at least 10% to recover
        if (errorSignalCounter < LOW_BATTERY_SIGNAL_COUNT) {
            lowBatterySound(BUZZER_PIN);
            errorSignalCounter++;
        }
        ledToggle();
        return;    // battery is not charged yet, wait some time and return
    }

    if (state == STATE_CURRENT_OVERLOAD && ((currentMillis - loadDisableTimeoutMs) < CURRENT_OVERLOAD_TIMEOUT_MS)) {
        currentTooHighSound(BUZZER_PIN);
        ledToggle();

        if ((currentMillis - sequentialOverloadMs) > (CURRENT_OVERLOAD_TIMEOUT_MS * MAX_SEQUENTIAL_OVERLOAD_COUNT)) {
            sequentialOverloadCount = 0;    // reset counter if overloads are not in time frame
            sequentialOverloadMs = 0;
        }

        if (sequentialOverloadCount >= MAX_SEQUENTIAL_OVERLOAD_COUNT) {
            fatalErrorSound(BUZZER_PIN);
            state = STATE_FATAL_ERROR; // too many sequential overloads, looks like a short circuit
            return;
        }
        sequentialOverloadMs = currentMillis;
        return;
    }

    if (state == STATE_OVER_TEMPERATURE && ((currentMillis - loadDisableTimeoutMs) < OVER_TEMPERATURE_TIMEOUT_MS)) {
        if (errorSignalCounter < OVER_TEMPERATURE_SIGNAL_COUNT) {
            overTemperatureSound(BUZZER_PIN);
            errorSignalCounter++;
        }
        ledToggle();
        return;
    }

    state = STATE_OK;
    systemUpSound(BUZZER_PIN);
    loadDisableTimeoutMs = 0;
    errorSignalCounter = 0;
}

static inline bool isDebugEnabled() {
    return digitalRead(DEBUG_ENABLE_PIN) == LOW;     // check that debug jumper is set to GND
}

static float getBatteryVoltage(uint16_t samplingCount) {
    float accumulatedValue = 0;
    for (uint16_t i = 0; i < samplingCount; i++) {
        float adcValue = analogRead(VOLTAGE_SENSOR_PIN);
        float outVoltage = (adcValue * MCU_SUPPLY_VOLTAGE) / ADC_RESOLUTION;
        float dividerVoltage = outVoltage / (R2 / (R1 + R2));
        accumulatedValue += dividerVoltage;
        delay(10);
    }
    return accumulatedValue / samplingCount;
}

static float getAcsLoadAmps(ACS712 acs) {
    float amps = (acs.mA_DC(CURRENT_READ_CYCLES) / 1000);
    return amps > 0 ? amps : 0.0f;
}

static inline void ledToggle() {
    digitalWrite(BUILD_IN_LED_PIN, !digitalRead(BUILD_IN_LED_PIN));
}

static inline void inverterSwitchOn() {
    digitalWrite(AC_INVERTER_SWITCH_PIN, HIGH);
}

static inline void inverterSwitchOff() {
    digitalWrite(AC_INVERTER_SWITCH_PIN, LOW);
}

static inline void dcLoadSwitchOn() {
    digitalWrite(DC_LOAD_SWITCH_PIN, HIGH);
    digitalWrite(BUILD_IN_LED_PIN, HIGH);
}

static inline void dcLoadSwitchOff() {
    digitalWrite(DC_LOAD_SWITCH_PIN, LOW);
    digitalWrite(BUILD_IN_LED_PIN, LOW);
}

static inline void disableAllOutputs() {
    inverterSwitchOff();
    dcLoadSwitchOff();
    setCoolingFanSpeed(COOLING_FAN_OFF);
}

static double getTemperature(LM35::LM35IC sensor) {
    double temperature = 0.0;
    for (uint8_t i = 0; i < TEMPERATURE_SAMPLING_COUNT; i++) {
        temperature += sensor.readTemp();
        delay(10);
    }
    return temperature / TEMPERATURE_SAMPLING_COUNT;
}

static inline TemperatureRange getTemperatureRange(double temperature) {
    if (temperature >= TEMP_RANGE_MAX) return TEMP_RANGE_MAX;
    if (temperature >= TEMP_RANGE_HIGH) return TEMP_RANGE_HIGH;
    if (temperature >= TEMP_RANGE_MEDIUM) return TEMP_RANGE_MEDIUM;
    if (temperature >= TEMP_RANGE_LOW) return TEMP_RANGE_LOW;
    return TEMP_RANGE_NORMAL;
}

static inline void setCoolingFanSpeed(CoolingFanSpeed adcValue) {
    analogWrite(COOLING_FAN_PIN, adcValue);
}

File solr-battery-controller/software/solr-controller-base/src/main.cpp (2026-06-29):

#include <Arduino.h>

#include "Sound.h"
#include "ACS712.h"
#include "BatteryCharger.h"

#define DEBUG_EN_PIN         9
#define BUILD_IN_LED_PIN    13
#define BUZZER_PIN          10
#define LOAD_OUT_PIN        11
#define CHARGER_PIN         3
#define BATTERY_OUT_PIN     5
#define ACS_SENSOR_PIN      A1
#define VOLTAGE_SENSOR_PIN  A0

#define MCU_SUPPLY_VOLTAGE              5.15f   // Manually measured value
#define ADC_RESOLUTION                  1023.0f

#define VOLTAGE_READ_COUNT              4
#define MIN_CURRENT_THRESHOLD_VALUE     0.1f
#define CURRENT_CORRECTION_COEFFICIENT  0.4f
#define CURRENT_OVERLOAD_TIMEOUT_MS     5000
#define LOW_BATTERY_SIGNAL_COUNT        10
#define ERROR_SIGNAL_DELAY_MS           500

static const BatteryType batteryType = SEALED_LEAD_ACID_BATTERY;
#define MAX_LOAD_CURRENT              30
#define MIN_BATTERY_VOLTAGE           getBatteryMinVoltage(batteryType)
#define BATTERY_RECOVERY_VOLTAGE      getBatteryRecoveryVoltage(batteryType)

/*
 * Two resistors divider of 30K and 7.5K
 *
 * Vbat     Vin      GND
 *  |        |        |
 *  +--[R1]--+--[R2]--+
 *
 *  R1 = 30kOhms
 *  R2 = 7.5kOhms
*/
static const float R1 = 30000;
static const float R2 = 7500;
static const float correctionFactor = 0.2f;

static uint8_t lowBatterySignalCounter = 0;
//  Arduino NANO has 5.0 volt with a max ADC value of 1023 steps
//  ACS712 30A uses 66mV per A
static ACS712 ACS712_CURRENT_SENSOR(ACS_SENSOR_PIN, MCU_SUPPLY_VOLTAGE, ADC_RESOLUTION, 66);
static uint32_t loadEnableTimeout = 0;
static uint32_t lowBatterySignalTimer = 0;
static uint32_t overCurrentSignalTimer = 0;

static float getPowerSupplyVoltage(uint16_t samplingCount);
static float getLoadAmps(ACS712 acs);

static inline void batteryOutOn();
static inline void batteryOutOff();
static inline void ledToggle();
static inline void ledOff();
static inline void outputRelayOn();
static inline void outputRelayOff();


void setup() {
    Serial.begin(9600);
    pinMode(BUILD_IN_LED_PIN, OUTPUT);
    pinMode(LOAD_OUT_PIN, OUTPUT);
    pinMode(BUZZER_PIN, OUTPUT);
    pinMode(CHARGER_PIN, OUTPUT);
    pinMode(DEBUG_EN_PIN, INPUT_PULLUP);
    pinMode(VOLTAGE_SENSOR_PIN, INPUT);

    outputRelayOff();// disable outputs at startup
    batteryOutOff();

    Serial.print("ACS712_LIB_VERSION: ");
    Serial.println(ACS712_LIB_VERSION);
    delay(100);

    ACS712_CURRENT_SENSOR.autoMidPointDC(10);
    ACS712_CURRENT_SENSOR.incMidPoint();
    ACS712_CURRENT_SENSOR.incMidPoint();
    ACS712_CURRENT_SENSOR.suppressNoise(true);

    Serial.print("ACS MidPoint= ");
    Serial.println(ACS712_CURRENT_SENSOR.getMidPoint());

    // stabilize values
    ACS712_CURRENT_SENSOR.mA_DC(150);
    getPowerSupplyVoltage(100);
    playStartupSound(BUZZER_PIN);
}

void loop() {

    float batteryVoltage = getPowerSupplyVoltage(VOLTAGE_READ_COUNT);
    SlaBatteryCharger *batteryCharger = handleSlaBatteryCharger(CHARGER_PIN, batteryVoltage);

    bool isDebugEnabled = digitalRead(DEBUG_EN_PIN) == LOW; // check that debug jumper is set to GND
    if (isDebugEnabled) {
        Serial.print("Battery V= ");
        Serial.println(batteryVoltage, 3);
        Serial.print(" | Mode: ");
        Serial.print(batteryCharger->chargeState == SLA_CHARGE_MAIN ? "MAIN" : "FLOAT");
        Serial.print(" | PWM: ");
        Serial.println(batteryCharger->pwmValue);
    }

    bool isLoadEnabled = digitalRead(LOAD_OUT_PIN) == LOW;
    if (isLoadEnabled && batteryVoltage <= MIN_BATTERY_VOLTAGE) {
        outputRelayOff();
        batteryOutOff();
    }

    if (!isLoadEnabled && batteryVoltage < BATTERY_RECOVERY_VOLTAGE) {
        if ((millis() - lowBatterySignalTimer) >= ERROR_SIGNAL_DELAY_MS) {
            ledToggle();

            if (lowBatterySignalCounter < LOW_BATTERY_SIGNAL_COUNT) {
                signalLowBattery(BUZZER_PIN);
                lowBatterySignalCounter++;
            }
            lowBatterySignalTimer = millis();
        }
        delay(50);    // slaBattery is not charged yet, wait some time and return
        return;
    }

    if (lowBatterySignalCounter != 0) {
        systemUpSound(BUZZER_PIN); // Battery charge is at least 10%
        lowBatterySignalCounter = 0;
        lowBatterySignalTimer = 0;
    }

    if (loadEnableTimeout == 0) {
        float loadAmps = getLoadAmps(ACS712_CURRENT_SENSOR);
        if (isDebugEnabled) {
            Serial.print("Load Amps= ");
            Serial.println(loadAmps, 3);
        }

        if (loadAmps > MAX_LOAD_CURRENT) {
            outputRelayOff();
            batteryOutOff();
            loadEnableTimeout = millis();
            return;
        }
        outputRelayOn();
        batteryOutOn();
        ledOff();
    }

    uint32_t currentMillis = millis();
    bool isACLoadEnabled = digitalRead(LOAD_OUT_PIN) == LOW;
    if (!isACLoadEnabled && ((currentMillis - loadEnableTimeout) < CURRENT_OVERLOAD_TIMEOUT_MS)) {
        if ((currentMillis - overCurrentSignalTimer) >= ERROR_SIGNAL_DELAY_MS) {// wait some time before the next error signal
            signalCurrentTooHigh(BUZZER_PIN);
            ledToggle();
            overCurrentSignalTimer = currentMillis;
        }
        return;
    }
    loadEnableTimeout = 0;
    delay(50);
}

static float getPowerSupplyVoltage(uint16_t samplingCount) {
    float accumulatedValue = 0;
    for (uint16_t i = 0; i < samplingCount; i++) {
        float adcValue = analogRead(VOLTAGE_SENSOR_PIN);
        float outVoltage = (adcValue * MCU_SUPPLY_VOLTAGE) / ADC_RESOLUTION;
        float dividerVoltage = outVoltage / (R2 / (R1 + R2));
        accumulatedValue += (dividerVoltage - correctionFactor);
        delay(10); // Sampling delay
    }
    return accumulatedValue / samplingCount;
}

static float getLoadAmps(ACS712 acs) {
    float amps = abs((acs.mA_DC(10) / 1000) + CURRENT_CORRECTION_COEFFICIENT);
    return (amps > MIN_CURRENT_THRESHOLD_VALUE) ? amps : 0.0f;
}

static inline void batteryOutOn() {
    digitalWrite(BATTERY_OUT_PIN, HIGH);
}

static inline void batteryOutOff() {
    digitalWrite(BATTERY_OUT_PIN, LOW);
}

static inline void ledToggle() {
    digitalWrite(BUILD_IN_LED_PIN, !digitalRead(BUILD_IN_LED_PIN));
}

static inline void ledOff() {
    digitalWrite(BUILD_IN_LED_PIN, LOW);
}

static inline void outputRelayOn() {
    digitalWrite(LOAD_OUT_PIN, LOW);
}

static inline void outputRelayOff() {
    digitalWrite(LOAD_OUT_PIN, HIGH);
}

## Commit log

2025-12-30 Initial implementation
    [Bill of Materials-inverter-12v-220v-500w.xlsx, Bill of Materials-tl494-pwm-module.xls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]
2025-12-30 Updated project structure
    [Bill of Materials-inverter-12v-220v-500w.xlsx, Bill of Materials-tl494-pwm-module.xls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]
2025-12-30 Solr battery controller implementation
    [Bill of Materials-inverter-12v-220v-500w.xlsx, Bill of Materials-solr-controller-base.xls, Bill of Materials-tl494-pwm-module.xls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]
2025-12-30 Add initial implementation of Solr battery controller and update readme
    [SnapEDApcb.PcbLib, SnapEDAsch.SchLib]
2026-01-03 Add battery type enum header and integrate battery voltage functions
2026-02-17 Update PCB files and metadata for new design specifications
    [Bill of Materials-inverter-12v-220v-500w.xlsx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]
2026-02-17 Add new log files for component designator changes and PCB updates
    [PCB.PcbDoc]
2026-04-01 Inverter board improvements: Button connector change and silkscreen fixes
    [Bill of Materials-inverter-12v-220v-500w.xlsx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]
2026-06-29 Solr button module: implementation
    [Bill of Materials-inverter-12v-220v-500w.xlsx, Bill of Materials-solr-button-module.xlsx, Bill of Materials-solr-controller-base.xls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]
2026-06-29 Resize PCB images in README
    Updated image sizes for top and bottom PCB in README.
2026-06-29 Fix typo in pinMode function for built-in LED pin
    [main.cpp]
2026-06-29 Update README: Add CV CC charger requirement and remove redundant battery chemistry mention
